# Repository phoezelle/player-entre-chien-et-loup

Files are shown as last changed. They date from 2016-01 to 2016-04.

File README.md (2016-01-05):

# player-entre-chien-et-loup
audio player for urban ballad http://www.cie-entrechienetloup.net/spectacles/verena-velvet.htm

The audio player work with 1 dedicated electronic card (cf pcb folder)
use atmega 328, vlsi vs1033/53, nordic NRF24L01+

You can control the system with a dedicated remote (cf pcb folder)
use atmega 328, hc595, nordic NRF24L01+, sparkfun LCD, keypad (optional)

use like arduino library
Player
Remote

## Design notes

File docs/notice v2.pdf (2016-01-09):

### Le nouveau fonctionnement type d’un dialogue player borne :

### Le player s’allume, il joue le morceau d’intro lxx_t00.mp3 (xx=00 pour le français) Toutes les bornes cherchent tous les players 5 fois par seconde. Elle diffuse sa

position dans le parcour (réglage télécommande posV).
Soit n la dernière position validée reçue par le player.

### Si un player passe à portée d’une borne il reçoit sa position. Il enregistre les informations de la borne si la position reçue est : - la prochaine position : n+1 - la suivante encore : n+2 si la piste en cours de lecture est arrivé à la fin du

temps incompressibles.

### De plus, au bout de X dialogue(s) réussi(s) (réglage télécommande nbV)

la borne lui donne l’accord de passer à la suite.

### Soit le temps incompressible est déjà passé, dans ce cas, il joue la piste correspondant à la nouvelle position n, sinon il attend la fin du temps incompressible

avant de jouer la piste correspondant à la nouvelle position n enregistrée.

### Il n’y a plus que les bornes qui occupent la bande passante, donc pas de soucis

avec des groupes de player en balade rapprochée.

### Il faut néanmoins veiller à un écartement correct des bornes (mini 50m en champ libre)

### Exemple de déroulement, usage ou non de l’interscène (pas de changement):

### Exemple de déroulement, personne très rapide, saut de la scène 3 :

### Pour le déclenchement au bon moment, il convient de jouer en premier lieu sur le placement des bornes (angles de rue, mise en retrait...) puis d’adapter les valeurs de puissances et d’accord consécutif pour limiter/étendre la zone de

déclenchement.
Ne pas oublier que le public ne sera pas isolé comme l’est souvent le régisseur.

### Player régie : il lit les pistes dans l’ordre comme les players normaux mais peut passer à la suite avant la fin du temps incompressible

K

V | K

scène 1
temps
incompressible

interscène

accord
borne 2

fade

scène 2

accord
borne 3
scène 3

accord
borne 4
scène 4

scène 1
temps
incompressible

interscène

accord
borne 2

fade

scène 2

accord
borne 3

accord
borne 4
scène 4

V

K

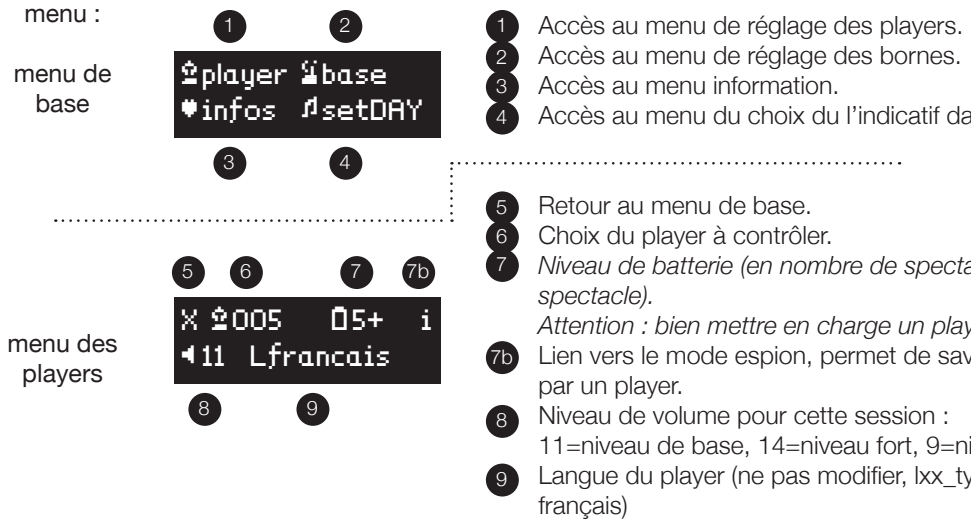
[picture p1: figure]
menu :; menu de base; menu des players; Accès au menu de réglage des players. Accès au menu de réglage des bornes. Accès au menu information.; Retour au menu de base. Choix du player à contrôler.; spectacle).; par un player. Niveau de volume pour cette session :; français); Kplayer Vbase Jinfos NsetDAY; 11 Lfrancais

menu des
player :
mode
espion

menu des
bornes

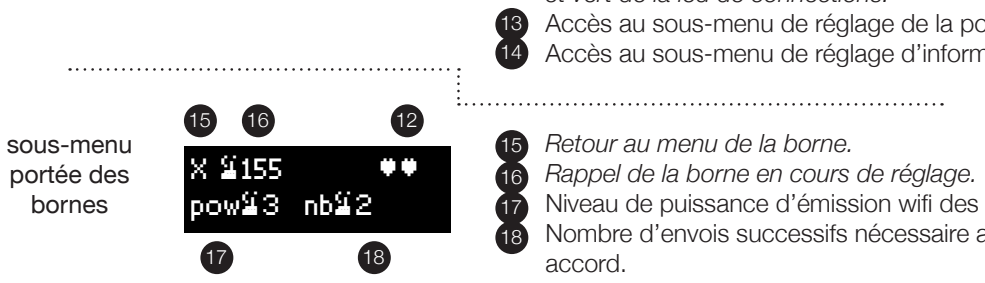
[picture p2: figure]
sous-menu portée des bornes; Retour au menu de la borne. Rappel de la borne en cours de réglage.; accord.; powV3 nbV2

sous-menu
audio des
bornes

menu
informations

Accès au menu du choix du l’indicatif day.

Niveau de batterie (en nombre de spectacle restant, environ 1h30 par Attention : bien mettre en charge un player dont la batterie est à 0. Lien vers le mode espion, permet de savoir quelles pistes ont été lues

11=niveau de base, 14=niveau fort, 9=niveau faible.
Langue du player (ne pas modifier, lxx_tyy.mp3 avec xx=00 pour le

Retour au menu du player connecté.
Donne les informations sur le pistes jouées par le player connecté préalablement.
par exemple, ce player a joué les pistes correspondantes aux positions 0,2,3,4,6,7 et a sauté les pistes correspondantes aux positions 1 et 5. (la position 0 est le message d’accueil)

Choix de la borne à contrôler.
Niveau de batterie (en nombre de jour restant).
Attention, la borne se met en veille au bout de 12h, il faut alors la réactiver en s’y connectant à l’aide de la télécommande.
Niveau de connections :
Z= borne hors de portée
JZ= borne à portée mais en train de négocier les accords consécutifs JJ= borne à portée et accord validé
Ces trois niveaux correspondent respectivement à l’état rouge, orange et vert de la led de connections.
Accès au sous-menu de réglage de la portée des bornes.
Accès au sous-menu de réglage d’information audio des bornes.

Niveau de puissance d’émission wifi des bornes de 0 à 3.
Nombre d’envois successifs nécessaire avant que la borne donne son

Position à laquelle la borne répond sur le parcours du spectacle Numéro de piste audio à lire (lxx_tyy.mp3, avec yy=numéro de piste). Temps incompressible de cette piste audio (max 8:30).
Temps de fade out de cette piste audio en seconde.

Vue synthétique des bornes à proximitées : ici les bornes 151 et 152 sont à portées mais seule la 151 à donnée son accord suite aux envois conssécutifs réussis.
Niveau de batterie de la télécommande. Une led rouge située à coté de la led orange power signale un niveau de batterie faible.
Les valeurs en italique ne peuvent être modifiées ou selectionnées. Une fois les modifications réalisées, ces dernière doivent être transférée au player ou à la borne à l’aide du bouton de synchronisation.

10

X V155 | c3 JJ
Vpower | Vtrack

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
X V155 posV05
N05 G5:10 f>G2

VJZ
X cbattery 3

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
19 19

22

22

J-JJJ-J--------
-------- | X
| 9b

9b

Un appui sur le clavier (de préférence sur X) nous emmène vers la sélection multiple de player
On peut ensuite procéder comme suit :
1. ajouter plusieurs player (5 max) à la liste, si on tape 1 + 3 + 6 Les valeurs choisies ensuite seront mises à jour pour les dispositifs 1,3 et 6.
2. sélectionner une plage de player, si on tape 1 à 25
les valeurs choisies ensuite seront mises à jour pour les dispositifs 1 à 25 inclus.
Ensuite on peut choisir la langue
taper L puis
0 = véréna velvet
1 = eden
2 = jordan
3 = franck
et/ou le volume
taper > puis entrer un chiffre entre 1 et 15
à tout moment on peut redémarrer la saisie à 0 en appuyant sur X
Si on est satisfait, on peut mettre à jour les players en appuyant sur GO

Exemple pour mettre à jour les players 1,5 et 54 au volume 8.

exemple pour mettre à jour les players 25 à 35 au volume 12 et à la langue jordan.

à noter qu’au redémarrage, si la langue enregistrée précedemment dans le player fait partie des 3 de estulà, des valeurs par défaut seront appliquées :
player 0 à 30 -> langue eden
player 31 à 60 -> langue jordan
player 61 à 101 -> langue franck
pour tous, au redémarrage, un volume de base est forcé à 11.

Choix du day, c’est un paramètre enregistré dans la télécommande qui sera mis à jour dans les player si et seulement si on leur modifie une autre valeur via le menu des players.

### Procédure pour le changement de DAY

(Permet de mieux suivre les statistiques)
Au début de la date :
1. allumer tous les players
2. changer de day dans les 2 télécommandes et noter le numéro choisi comme associé à cette date
3. avec la télécommande++, sélectionner les player de 1 à 100, mettre le volume à 1, valider.
4. la télécommande devrait mettre à jour tous les players.
5. éteindre les players.

menu :
menu saisie
clavier

exemple 1

exemple 2

menu du
choix du
Day
5 | 25 | 25

26

X DAY 01

K0

K1+5+54
8 L

K25->35
12 L jordan

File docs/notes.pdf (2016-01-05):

# premières petites notes

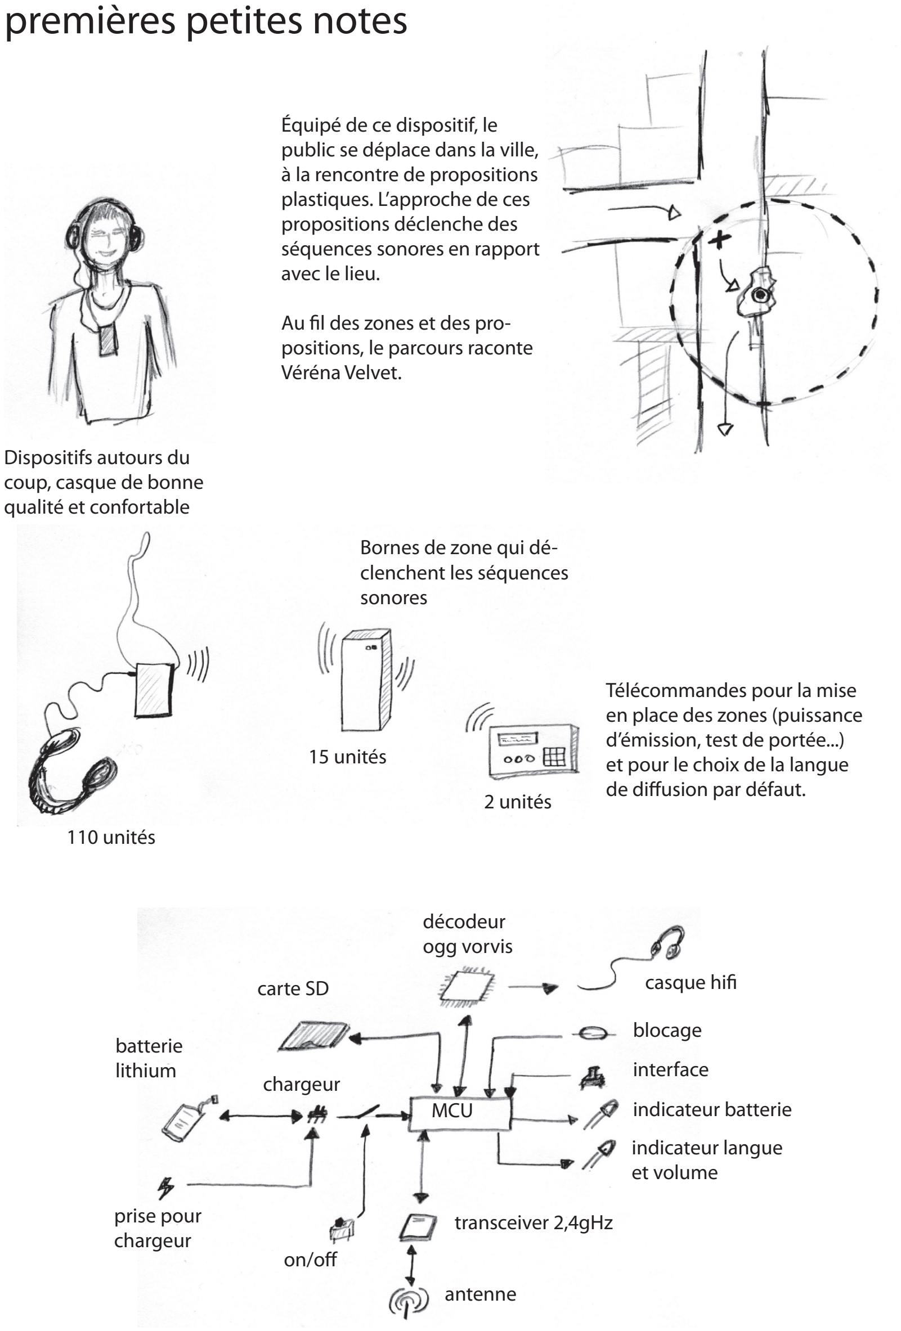
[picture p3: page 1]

Dispositifs autours du
coup, casque de bonne
qualité et confortable

Équipé de ce dispositif, le public se déplace dans la ville, à la rencontre de propositions plastiques. L’approche de ces propositions déclenche des séquences sonores en rapport avec le lieu.

Au fil des zones et des propositions, le parcours raconte Véréna Velvet.

Bornes de zone qui déclenchent les séquences
sonores

15 unités

110 unités

2 unités

Télécommandes pour la mise en place des zones (puissance d’émission, test de portée...) et pour le choix de la langue de diffusion par défaut.

carte SD

décodeur
ogg vorvis
casque hifi

blocage
interface
indicateur batterie
indicateur langue
et volume

transceiver 2,4gHz

MCU

antenne

on/off

chargeur

batterie
lithium

prise pour
chargeur

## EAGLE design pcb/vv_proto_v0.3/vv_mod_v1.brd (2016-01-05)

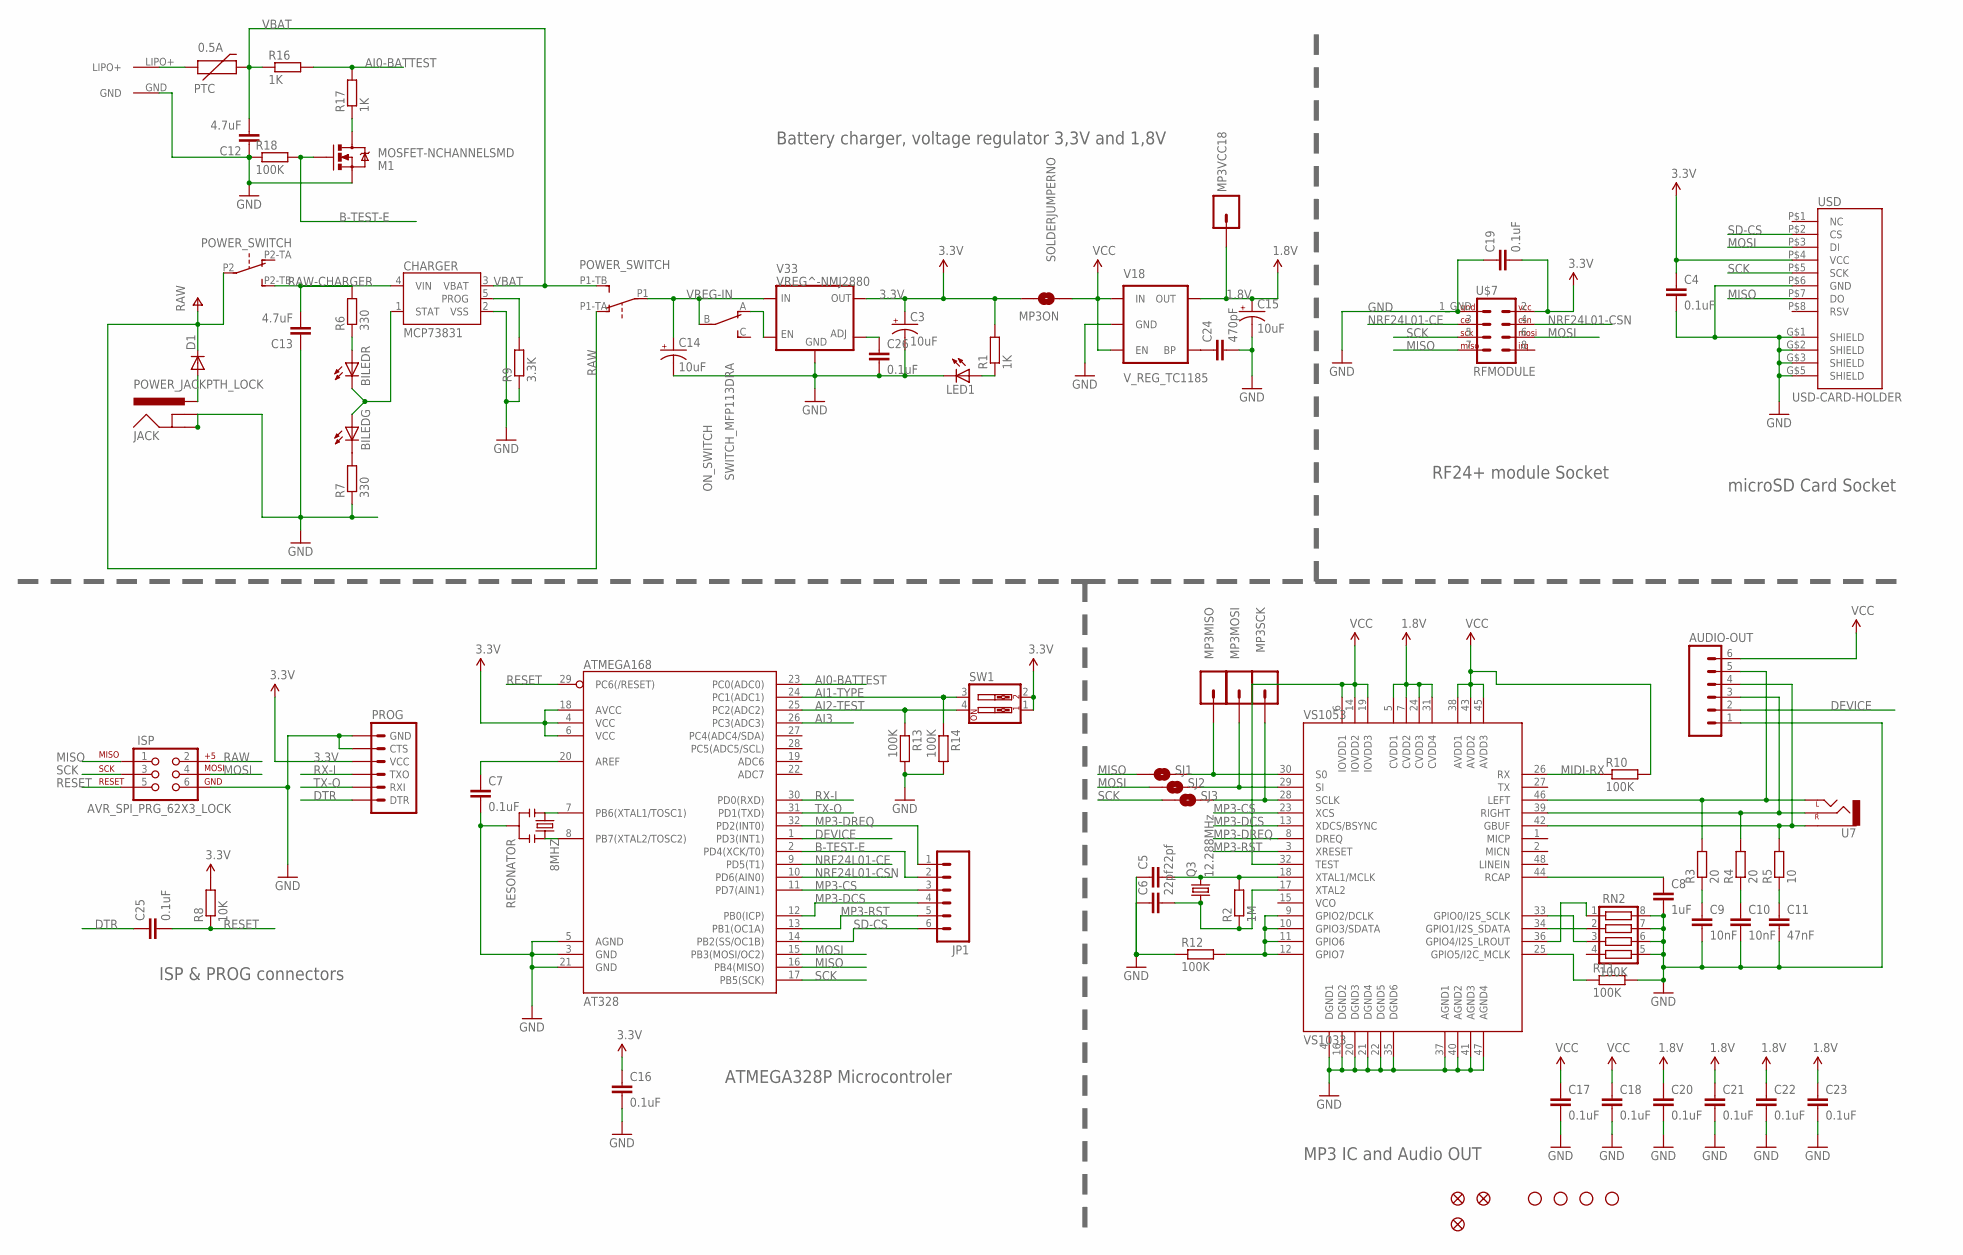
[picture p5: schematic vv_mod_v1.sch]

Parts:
0.5A: PTC; PTC-1210
8MHZ: RESONATOR; RESONATOR_7MM
AT328: ATMEGA168; TQFP32-08
AUDIO-OUT: M06LOCK; 1X06_LOCK
BILED: BILED; 2XLED
C3, C14, C15: 10uF; EIA3216
C4, C7, C16, C17, C18, C19, C20, C21, C22, C23, C25, C26: 0.1uF; C0805
C5, C6: 22pf; C0603
C8: 1uF; C0603
C9, C10: 10nF; C0603
C11: 47nF; C0603
C12, C13: 4.7uF; C0603
C24: 470pF; C0603
CHARGER: MCP73831; SOT23-5
D1: DIODESMA-KIT; SMA-DIODE-KIT
ISP: AVR_SPI_PRG_62X3_LOCK; 2X3_LOCK
JACK: POWER_JACKPTH_LOCK; POWER_JACK_PTH_LOCK
JP1: M06SIP; 1X06
JP2, JP3, JP8: FIDUCIAL1X2.5; FIDUCIAL-1X2.5
JP4, JP5, JP6, JP7: STAND-OFF
LED1: LED1206; LED-1206
M1: MOSFET-NCHANNELSMD; SOT23-3
MP3MISO, MP3MOSI, MP3SCK, MP3VCC18: M01SMD-4.5X1.5; PAD-1.5X4.5
MP3ON: SOLDERJUMPERNO; SJ_2S-NO
ON_SWITCH: SWITCH_MFP113DRA; SWITCH
POWER_SWITCH: JS202011SCQNPIN; SWITCHPOWER
PROG: ARDUINO_SERIAL_PROGRAMLOCK; 1X06_LOCK
Q3: 12.288MHz; HC49UP
R1, R16, R17: 1K; R0603
R2: 1M; R0603
R3, R4: 20; R0603
R5: 10; R0603
R6, R7: 330; R0805
R8: 10K; R0603
R9: 3.3K; R0603
R10, R11, R12, R13, R14, R18: 100K; R0805
RN2: 100K; CTS742C083
SJ1, SJ2, SJ3: SOLDERJUMPERNO; SJ_2S-NO
SW1: SW_DIP-2; DIPSWITCH-02
U7: AUDIO-JACKPTH; AUDIO-JACK
U$7: RFMODULE; 2X5_RFMODULE
U$8: LIPO_PAD; 2X1_LIPO_PAD
USD: USD-CARD-HOLDER; MICRO-SD-MOLEX-47579-001
V18: V_REG_TC1185; SOT23-5
V33: VREG^-NMJ2880; SOT-89
VS1053: VS1033; LQFP-48

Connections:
1.8V: C15.A (+), C20.1, C21.1, C22.1, C23.1, MP3VCC18.P$1, V18.5 (OUT), VS1053.5 (CVDD1), VS1053.7 (CVDD2), VS1053.24 (CVDD3), VS1053.31 (CVDD4)
3.3V: AT328.4 (VCC), AT328.6 (VCC), AT328.18 (AVCC), C3.A (+), C4.1, C16.1, C19.2, MP3ON.2, PROG.4 (VCC), R1.2, R8.2, SW1.1, SW1.2, U$7.2 (VCC), USD.P$4 (VCC), V33.4 (OUT)
100K-1: R12.2, VS1053.9 (GPIO2/DCLK), VS1053.10 (GPIO3/SDATA), VS1053.11 (GPIO6), VS1053.12 (GPIO7)
AI0-BATTEST: AT328.23 (PC0(ADC0)), R16.2, R17.2
AI1-TYPE: AT328.24 (PC1(ADC1)), R14.1, SW1.3
AI2-TEST: AT328.25 (PC2(ADC2)), R13.1, SW1.4
AI3: AT328.26 (PC3(ADC3))
AREF: AT328.20 (AREF), C7.1
B-TEST-E: AT328.2 (PD4(XCK/T0)), JP1.2, M1.1 (G), R18.2
DEVICE: AT328.1 (PD3(INT1)), AUDIO-OUT.2
DTR: C25.1, PROG.1 (DTR)
GBUF: AUDIO-OUT.4, R5.2, U7.SLEEVE, VS1053.42 (GBUF)
GND: 8MHZ.2, AT328.3 (GND), AT328.5 (AGND), AT328.21 (GND), AUDIO-OUT.1, C3.C (-), C4.2, C5.1, C6.1, C7.2, C8.2, C9.2, C10.2, C11.2, C12.1, C13.1, C14.C (-), C15.C (-), C16.2, C17.2, C18.2, C19.1, C20.2, C21.2, C22.2, C23.2, C24.2, C26.2, CHARGER.2 (VSS), ISP.6, JACK.GND, JACK.GNDBREAK, LED1.C, M1.2 (S), PROG.5 (CTS), PROG.6 (GND), R7.1, R9.1, R11.2, R12.1, R13.2, R14.2, R18.1, RN2.5, RN2.6, RN2.7, RN2.8, U$7.1_GND (GND), U$8.GND, USD.G$1 (SHIELD), USD.G$2 (SHIELD), USD.G$3 (SHIELD), USD.G$5 (SHIELD), USD.P$6 (GND), V18.2 (GND), V33.2 (GND), VS1053.4 (DGND1), VS1053.16 (DGND2), VS1053.20 (DGND3), VS1053.21 (DGND4), VS1053.22 (DGND5), VS1053.35 (DGND6), VS1053.37 (AGND1), VS1053.40 (AGND2), VS1053.41 (AGND3), VS1053.47 (AGND4)
LEFT: AUDIO-OUT.5, R3.2, U7.TIP (LEFT), VS1053.46 (LEFT)
MIDI-RX: R10.1, VS1053.26 (RX)
MISO: AT328.16 (PB4(MISO)), ISP.1, SJ1.1, U$7.7 (MISO), USD.P$7 (DO)
MISOMP3: MP3MISO.P$1, SJ1.2, VS1053.30 (S0)
MOSI: AT328.15 (PB3(MOSI/OC2)), ISP.4, SJ2.1, U$7.6 (MOSI), USD.P$3 (DI)
MOSIMP3: MP3MOSI.P$1, SJ2.2, VS1053.29 (SI)
MP3-CS: AT328.11 (PD7(AIN1)), JP1.3, VS1053.23 (XCS)
MP3-DCS: AT328.12 (PB0(ICP)), JP1.4, VS1053.13 (XDCS/BSYNC)
MP3-DREQ: AT328.32 (PD2(INT0)), JP1.1, VS1053.8 (DREQ)
MP3-RST: AT328.13 (PB1(OC1A)), JP1.5, VS1053.3 (XRESET)
unnamed: ON_SWITCH.A (O), V33.1 (EN)
unnamed: C26.1, V33.3 (ADJ)
unnamed: RN2.1, VS1053.36 (GPIO4/I2S_LROUT)
unnamed: LED1.A, R1.1
unnamed: RN2.3, VS1053.33 (GPIO0/I2S_SCLK)
unnamed: R11.1, VS1053.25 (GPIO5/I2C_MCLK)
unnamed: 8MHZ.1, AT328.7 (PB6(XTAL1/TOSC1))
unnamed: 8MHZ.3, AT328.8 (PB7(XTAL2/TOSC2))
unnamed: RN2.2, VS1053.34 (GPIO1/I2S_SDATA)
unnamed: D1.A, JACK.PWR
unnamed: C9.1, R3.1
unnamed: C10.1, R4.1
unnamed: C11.1, R5.1
unnamed: BILED.A2 (A), R6.1
unnamed: BILED.C3 (C), R7.2
unnamed: CHARGER.5 (PROG), R9.2
unnamed: M1.3 (D), R17.1
unnamed: C24.1, V18.4 (BP)
NRF24L01-CE: AT328.9 (PD5(T1)), U$7.3 (CE)
NRF24L01-CSN: AT328.10 (PD6(AIN0)), U$7.4 (CSN)
RAW: D1.C, ISP.2, POWER_SWITCH.P1-TA (O), POWER_SWITCH.P2
RAW-CHARGER: C13.2, CHARGER.4 (VIN), POWER_SWITCH.P2-TB (S), R6.2
RCAP: C8.1, VS1053.44 (RCAP)
RESET: AT328.29 (PC6(/RESET)), C25.2, ISP.5, R8.1
RIGHT: AUDIO-OUT.3, R4.2, U7.RING (RIGHT), VS1053.39 (RIGHT)
RX-I: AT328.30 (PD0(RXD)), PROG.3 (TXO)
SCK: AT328.17 (PB5(SCK)), ISP.3, SJ3.1, U$7.5 (SCK), USD.P$5 (SCK)
SCKMP3: MP3SCK.P$1, SJ3.2, VS1053.28 (SCLK)
SD-CS: AT328.14 (PB2(SS/OC1B)), JP1.6, USD.P$2 (CS)
STAT: BILED.A1 (A), BILED.C4 (C), CHARGER.1 (STAT)
TX-O: AT328.31 (PD1(TXD)), PROG.2 (RXI)
VBAT: 0.5A.2, C12.2, CHARGER.3 (VBAT), POWER_SWITCH.P1-TB (S), R16.1
VBAT-RAW: 0.5A.1, U$8.LIPO+
VCC: AUDIO-OUT.6, C17.1, C18.1, MP3ON.1, R10.2, V18.1 (IN), V18.3 (EN), VS1053.6 (IOVDD1), VS1053.14 (IOVDD2), VS1053.19 (IOVDD3), VS1053.32 (TEST), VS1053.38 (AVDD1), VS1053.43 (AVDD2), VS1053.45 (AVDD3)
VREG-IN: C14.A (+), ON_SWITCH.B, POWER_SWITCH.P1, V33.5 (IN)
XTAL1_MP3: C5.2, Q3.2, R2.2, VS1053.18 (XTAL1/MCLK)
XTAL2_MP3: C6.2, Q3.1, R2.1, VS1053.17 (XTAL2)

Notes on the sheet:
ISP & PROG connectors
MP3 IC and Audio OUT
microSD Card Socket
RF24+ module Socket
Battery charger, voltage regulator 3,3V and 1,8V
ATMEGA328P Microcontroler

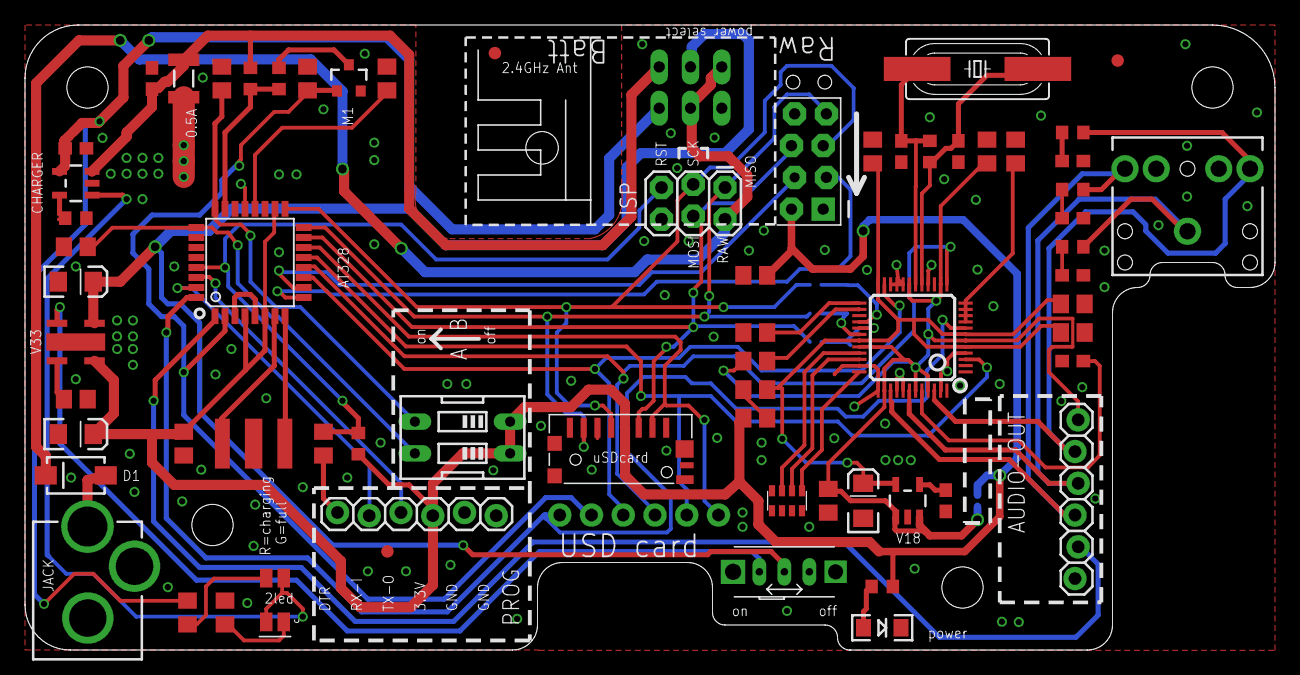
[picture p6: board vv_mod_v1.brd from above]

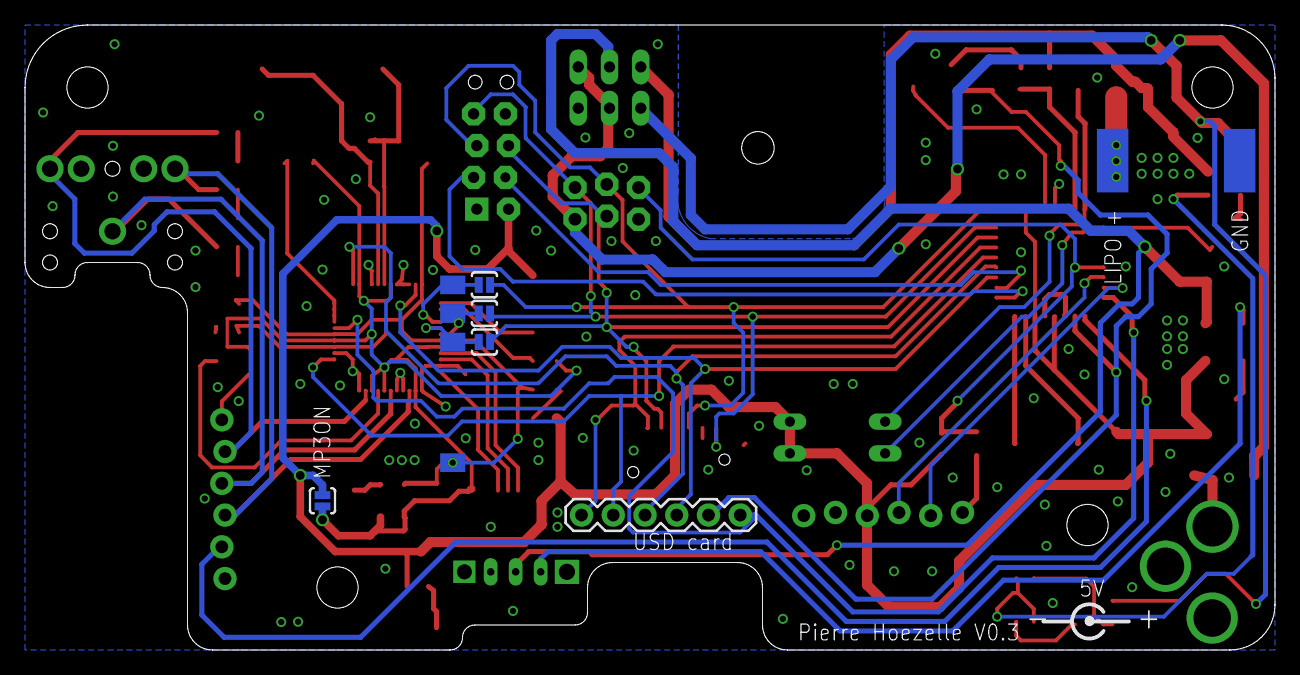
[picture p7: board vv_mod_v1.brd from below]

Board: 2 copper layers, 100.0 x 50.0 mm, 81 parts (9 on the bottom side), 59 nets.

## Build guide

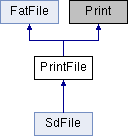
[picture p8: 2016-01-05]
Player/doc/html/class_print_file.png

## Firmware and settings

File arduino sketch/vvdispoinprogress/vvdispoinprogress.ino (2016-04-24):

#include <stddef.h>
#include <avr/pgmspace.h>

#include <SPI.h>
#include <EEPROM.h>

#include "printf.h"

#include "nRF24L01.h"
#include "RF24.h"


#include <SdFat.h>
#include <SdFatUtil.h> 

#include <ThePlayer.h>

//#include <MemoryFree.h>

#include <avr/sleep.h>
#include <avr/wdt.h>




// watchdog interrupt
ISR (WDT_vect) 
{
   wdt_disable();  // disable watchdog
}  // end of WDT_vect

const byte theInitID=154;

ThePlayer myPlayer;




void setup() {
  Serial.begin(115200);
  delay(20);
  Serial.println("ON");
  printf_begin();
  //printf_P(PSTR("printf ok\n\r"));
  delay(100);
  myPlayer.init(theInitID); //init the player
}

void loop(){

  myPlayer.routine();
  //delay(500);
  //printf(".");

}

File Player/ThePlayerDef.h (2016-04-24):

/*! \file ThePlayerDef.h
 \brief settings
 
 */

#ifndef __ThePlayerDef_h__
#define __ThePlayerDef_h__



/**
 * @name general settings
 *
 */
/**@{*/
#define NB_LANGAGE_MAX 10
#define NB_TRACK_MAX 99

#define DEFAULT_VOLUME 11 /**< \brief volume is set default each startup*/

#define TIME_BEFORE_BASE_SLEEP 720 /**< \brief in minutes default 720min*/

/**@}*/

// *******************************************
/**
 * @name hardware IO pin settings
 *
 */
/**@{*/

//IO pin
#define MASTER_DEVICE 3  /**< \brief sensor or actuator for further use*/
#define MASTER_BTEST 4 /**< \brief OUTPUT active resitor bridge for battery test plus a led*/

#define MASTER_RF24_CE 5 /**< \brief RF24 pin chip enable*/
#define MASTER_RF24_CS 6 /**< \brief RF24 pin chip select*/

//MP3 Player Shield pin mapping. See the schematic
#define MP3_XCS 7 /**< \brief Control Chip Select Pin (for accessing SPI Control/Status registers)*/
#define MP3_XDCS 8 /**< \brief Data Chip Select / BSYNC Pin*/
#define MP3_DREQ 2 /**< \brief Data Request Pin: Player asks for more data*/
#define MP3_RESET 9 /**< \brief Reset is active low*/

#define SD_CS 10 /**< \brief Control uSD card Chip Select Pin (for accessing SPI read to SD card)*/
//Analog pin
#define MASTER_ABATT 0 /**< \brief analog pin for battery test*/
#define MASTER_AROLE1 1 /**< \brief analog pin for type select switch (sation = off / base = on)*/
#define MASTER_AROLE2 2 /**< \brief analog pin for verbose and serial debugging switch (active = on)*/

/**@}*/

// ********************************************
/**
 * @name dipswitch state on boot
 *
 */
/**@{*/

//State depends of switch
#define PLAYER 0x00
#define BASE 0x01
#define PLAYER_AUTO 0x02
#define PLAYER_CUSTOM 0x03

/**@}*/
/**
 * @name batterie analog value
 *
 */
/**@{*/

//BATTERY ANALOG CORECTION
#define MASTER_ABATT_5 598
#define MASTER_ABATT_4 589
#define MASTER_ABATT_3 580
#define MASTER_ABATT_2 577
#define MASTER_ABATT_1 564

/**@}*/

//other
#define TRUE  0
#define FALSE  1

/**
 * @name VS1033 address register
 *
 */
/**@{*/

//VS10xx SCI Registers
#define SCI_MODE 0x00
#define SCI_STATUS 0x01
#define SCI_BASS 0x02
#define SCI_CLOCKF 0x03
#define SCI_DECODE_TIME 0x04
#define SCI_AUDATA 0x05
#define SCI_WRAM 0x06
#define SCI_WRAMADDR 0x07
#define SCI_HDAT0 0x08
#define SCI_HDAT1 0x09
#define SCI_AIADDR 0x0A
#define SCI_VOL 0x0B
#define SCI_AICTRL0 0x0C
#define SCI_AICTRL1 0x0D
#define SCI_AICTRL2 0x0E
#define SCI_AICTRL3 0x0F

/**@}*/


//globals
#define BASE_POSITION_RF_ADRESS_OFFSET 0xC8 //200

//********************************************
/**
 * @name RF communication code
 *
 */
/**@{*/
#define CODE_GET_VALUE 0x0F
#define CODE_ACK_RESPONSE 0x0E
#define CODE_ACK_RESPONSE_SET_OK 0x0D
#define CODE_ACK_RESPONSE_MEMORY 0x08
#define CODE_GET_MEMORY 0x07
#define CODE_SET_ID 0x0B
#define CODE_SET_VALUE 0x0A
#define CODE_DISPO_TRY_CONNECT 0x05
#define CODE_BASE_TRY_CONNECT 0x04
#define CODE_BASE_SAY_OK 0x03
#define CODE_ACK_PLAYER_WAITING 0x02
#define CODE_ACK_PLAYER_GO 0x01

/**@}*/

//********************************************
/**
 * @name index and maximum for value array storage
 *
 */
/**@{*/
#define VALUE_ID_DISPO 0
#define MAX_VALUE_ID 255

#define VALUE_VOLUME 1
#define MAX_VALUE_VOLUME 15

#define VALUE_LANG 2
#define MAX_VALUE_LANG 5

#define VALUE_TRACK 3
#define MAX_VALUE_TRACK 30

#define VALUE_MIN_TIME 4
#define MAX_VALUE_MIN_TIME 255

#define VALUE_FADE_OUT_TIME 5
#define MAX_VALUE_FADE_OUT_TIME 10

#define VALUE_BASE_POSITION 6
#define MAX_VALUE_BASE_POSITION 30

#define VALUE_BASE_POWER 7
#define MAX_VALUE_BASE_POWER 4

#define VALUE_BASE_CONSECUTIVE_TRANSMIT_TO_GO 8
#define MAX_VALUE_BASE_CONSECUTIVE_TRANSMIT_TO_GO 7

#define VALUE_DAY 9
#define MAX_VALUE_DAY 31

#define VALUE_BATTERY 10
#define MAX_VALUE_BATTERY 6



//other data

#define ROLE 11

#define OK_SD 12

#define OK_RF24 13

#define OK_MP3 14


#define NB_VALUE_TOTAL 15

#define NB_VALUE_STORED 11

/**@}*/





//second tab of value for base or
/**
 * @name second value array for base
 *
 */
/**@{*/

#define PLAYING_BASE_POSITION 0
#define PLAYING_TRACK 1
#define PLAYING_MIN_TIME 2
#define PLAYING_FADE_OUT_TIME 3
#define PLAYING_ID_BASE 4

#define NB_INFO_TRACK 5


#define PLAYER 0x00
#define BASE 0x01
#define PLAYER_AUTO 0x02
#define PLAYER_CUSTOM 0x03

/**@}*/


#define BYTETOBINARYPATTERN "%d%d%d%d%d%d%d%d" 
/** macro for display binary value*/
#define BYTETOBINARY(byte)  \
(byte & 0x80 ? 1 : 0), \
(byte & 0x40 ? 1 : 0), \
(byte & 0x20 ? 1 : 0), \
(byte & 0x10 ? 1 : 0), \
(byte & 0x08 ? 1 : 0), \
(byte & 0x04 ? 1 : 0), \
(byte & 0x02 ? 1 : 0), \
(byte & 0x01 ? 1 : 0) 





#endif

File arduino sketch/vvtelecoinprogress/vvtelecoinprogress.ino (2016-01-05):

#include <stddef.h>
#include <avr/pgmspace.h>

#include <SPI.h>
//Add EEPROM librarie
#include <EEPROM.h>

#include "printf.h"

#include <SoftwareSerial.h>
#include "Bounce.h"
#include <TheRemote.h>




#include "nRF24L01.h"
#include "RF24.h"

//#include <Menu.h>

//#include <LCD.h>

#define TELECO_ID 251



TheRemote myRemote;

void setup() {                
  Serial.begin(9600);
  delay(20);
  Serial.println("STARTUP COCO");
    printf_begin();
  printf_P(PSTR("printf ok\n\r"));
  delay(100);
  myRemote.init(TELECO_ID);
  attachInterrupt(0,doEncoderA, FALLING);

}

void loop() {
  myRemote.routine();    
}

void doEncoderA(){
  myRemote.doEncoderA();
}
